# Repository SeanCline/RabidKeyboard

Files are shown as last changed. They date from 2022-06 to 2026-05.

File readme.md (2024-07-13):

# RabidKeyboard

This project is an ode to the old-school Cooler Master [QuickFire Rapid](https://deskthority.net/wiki/Cooler_Master_QuickFire_Rapid) TKL keyboard -- a board that introduced many people to the mechanical keyboard hobby years ago.

Over time, upgrade parts for these old mechanical keyboards have become hard to find. This project attempts to solve that by providing PCB designs that can be manufactured by services like [JLCPCB](https://jlcpcb.com/) or [PCBWay](https://www.pcbway.com/).

With the PCBs in this repository, you could:
 - Build a TKL keyboard from scratch.
 - Replace the mini-USB plug with USB-C on your Cooler Master QFR.
 - Replace the PCB in your QFR (or compatible) with a custom design running the [KMK firmware](https://github.com/KMKfw/kmk_firmware).
 - Replace the plate in your TKL keyboard with one made of FR-4 and support for more stabilizers. (Stock Costar, Cherry Plate mount, or PCB mount when the PCB is also replaced.)

## PCB
The PCB is designed in [KiCad](https://www.kicad.org/) to be easily soldered by hand. At its heart is the [RP2040 Stamp](https://www.lectronz.com/products/rp2040-stamp), which fits nicely beside the arrow keys.

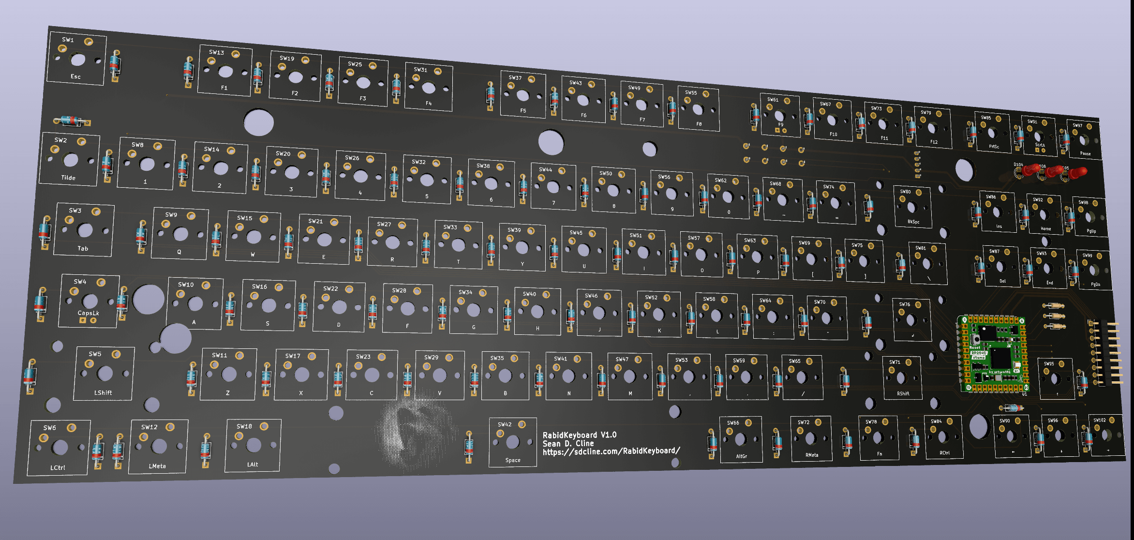
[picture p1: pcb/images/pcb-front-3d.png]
PCB 3D Render


## Plate
The plate is just a PCB without any copper traces. When sending it for manufacture, you can select the thickness of FR-4 to get the level of flex you like.

It's generated by copying the User.1 layer out of the PCB design and changing the layer to Edge.Cuts. The keyswitch footprints use the User.1 layer for the plate cutout which makes sure the plate cutouts always line up with the key switch location on the PCB.

> Note: This abuses the routing capabilities of a PCB manufacturer, so they'll likely charge extra for their trouble.

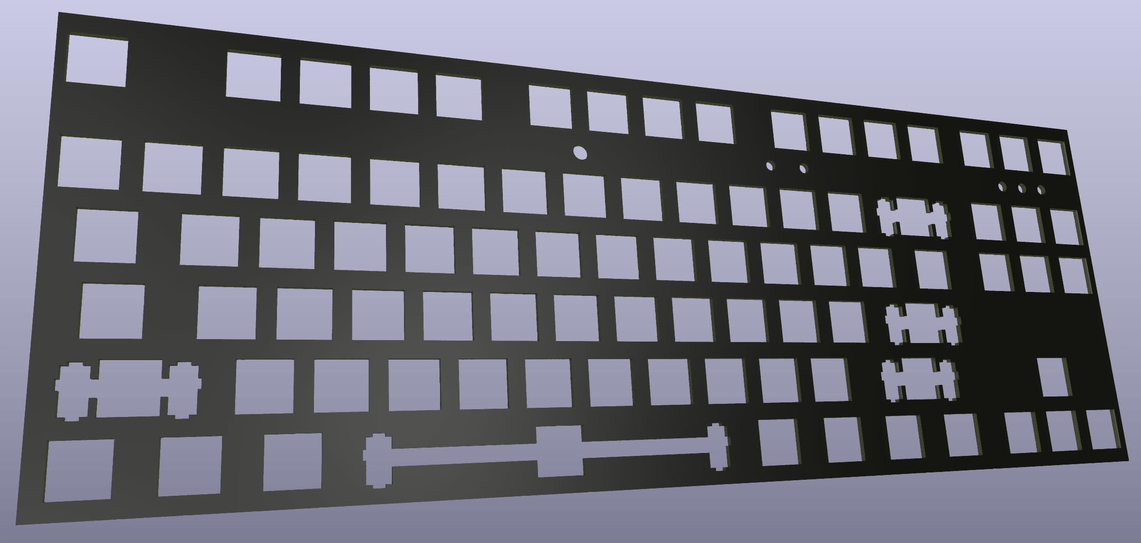
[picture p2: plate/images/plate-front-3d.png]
Plate 3D Render


## Costar USB-C Daughterboard
This PCB replaces the original mini-USB daughterboard in the Cooler Master QFR. Mounting holes match the [original PCB](reference/Quickfire%20Rapid/USB%20Daughterboard%20-%20Front.jpg) so it's a drop-in replacement. A little bit of filing is required to widen the mini-USB hole the width of the USB-C port.

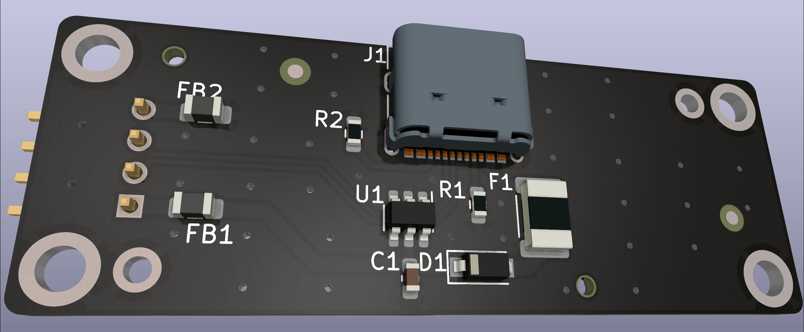
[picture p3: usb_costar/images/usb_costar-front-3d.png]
Costar USB-C Front 3D Render

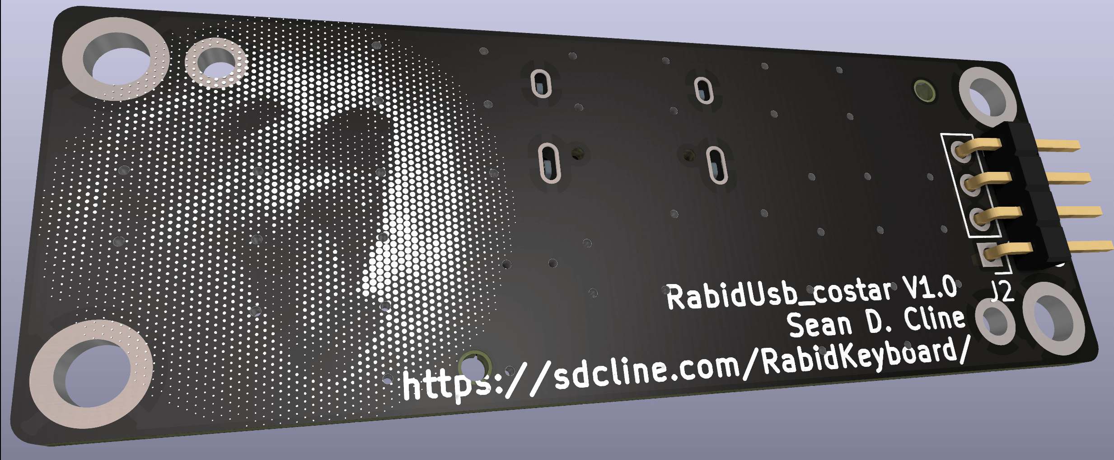
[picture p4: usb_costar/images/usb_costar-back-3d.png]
Costar USB-C Back 3D Render


## YMDK USB-C Daughterboard
Just like the Cooler Master QFR, Filco Majestouch 2, and KBParadise V80, the RabidKeyboard PCB in this repo fits into the YMDK F87 aluminum case.
[[Amazon]](https://amzn.com/dp/B06XNTWXWL)
[[AliExpress]](https://www.aliexpress.us/item/2251832431251957.html)
[[Ymdkey]](https://ymdkey.com/products/f87-tkl-cnc-anodized-aluminum-case-for-filco-cm-cooler-master-87-tenkeyless)

Unfortunately, the USB daughterboard that [comes with](reference/YMDK/YMDK%20Usb%20-%20Back.png) the YMDK F87 case lacks the [required 5.1k resistors](https://hackaday.com/2023/01/04/all-about-usb-c-resistors-and-emarkers/). It works fine when plugged in using a USB-C to Type-A cable, but does not function when plugged in using a USB-C to USB-C cable. It also lacks protection circuitry. The design in this repository is a drop in replacement with some improvements:
 - 5.1k CC1 and CC2 sense resistors to work with USB-C cables.
 - [TVS diodes](https://en.wikipedia.org/wiki/Surge_protector#Transient_voltage_suppressor) to keep static shocks from reaching the microcontroller.
 - 500mA polyfuse to protect from short circuits.
 - Reverse polarity protection diode.
 - Ferrite beads to reduce high frequency EMI.

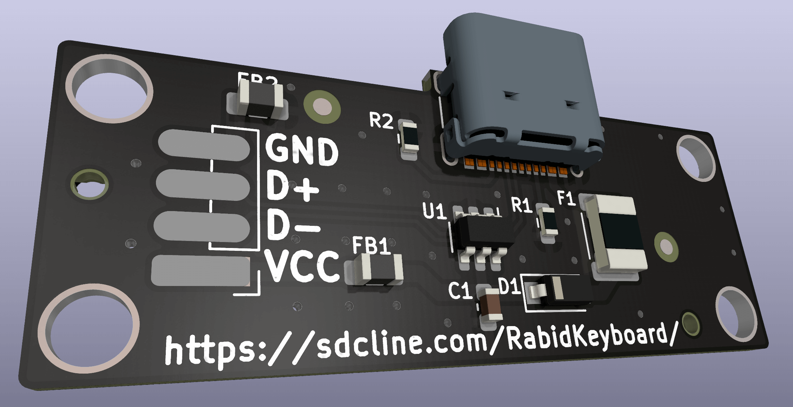
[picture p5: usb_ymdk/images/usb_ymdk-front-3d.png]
YMDK USB-C Front 3D Render

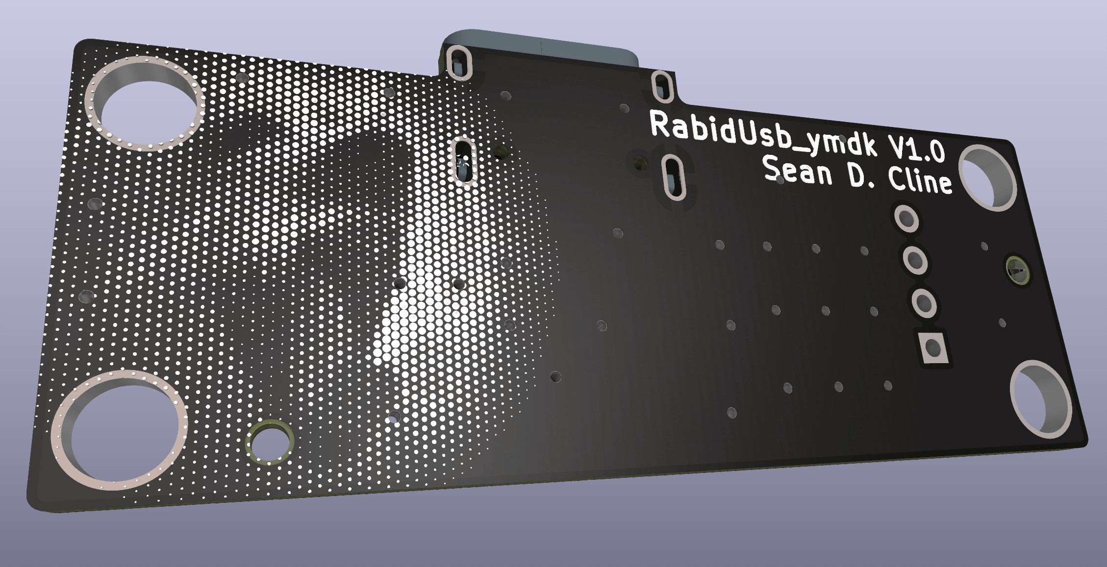
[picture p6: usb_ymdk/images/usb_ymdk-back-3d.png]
YMDK USB-C Back 3D Render


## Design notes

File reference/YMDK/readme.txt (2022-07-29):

These reference photos come from the YMDK F87, an anodized aluminum case for the Cooler Master Quickfire Rapid or Filco Majestouch TKL keyboard.

https://www.aliexpress.com/item/2251832781338162.html
https://www.aliexpress.com/item/2251832431251957.html
https://ymdkey.com/collections/case/products/cnc-anodized-aluminum-case-shell-for-filco-cm-cooler-master-87-tenkeyless-mechanical-keyboard-including-detachable-usb-m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

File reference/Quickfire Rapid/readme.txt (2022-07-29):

These are high-quality scans of the old school Cooler Master Quickfire Rapid TKL Keyboard.
The board was manufactured by Costar, the same company the manufactured the popular Filco Majestouch, WASD V1, Das Keyboard III, and Rosewill RK9000.

https://deskthority.net/wiki/Cooler_Master_QuickFire_Rapid
https://deskthority.net/wiki/Costar
https://www.coolermaster.com/catalog/peripheral/keyboards/quick-fire-rapid/

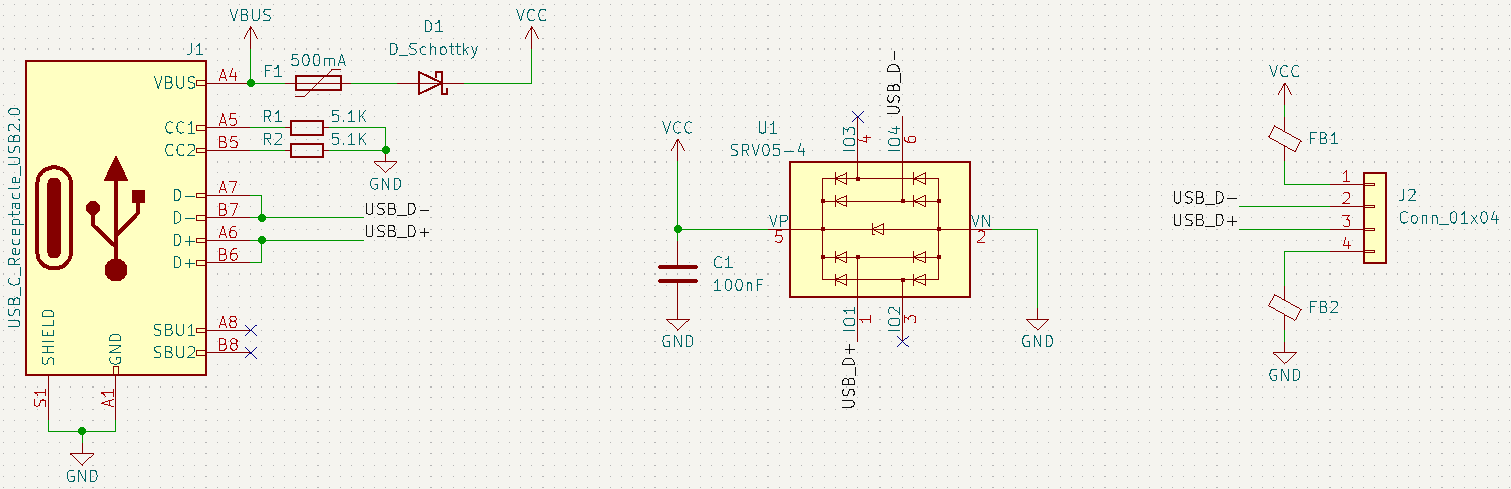
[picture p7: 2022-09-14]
usb_ymdk/images/usb_ymdk-schematic.png

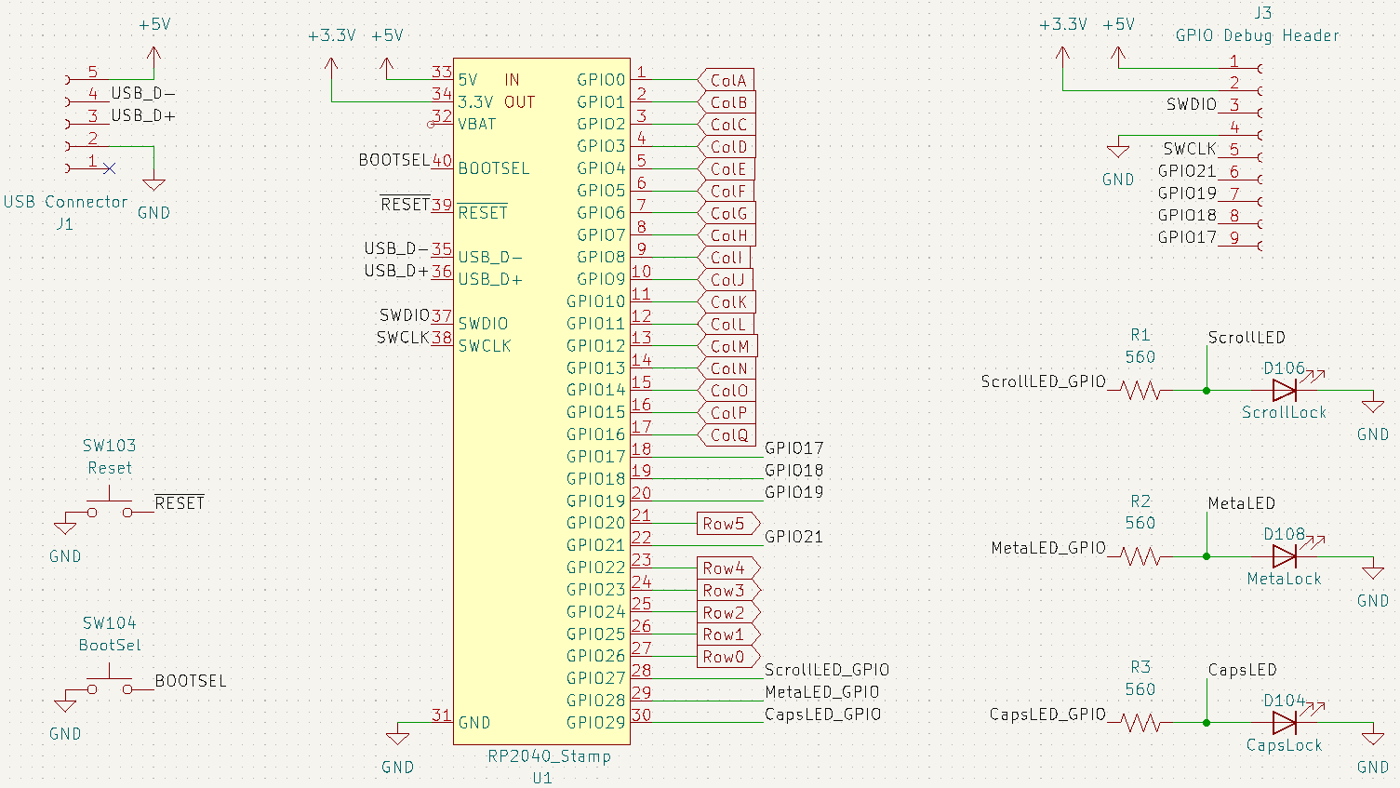
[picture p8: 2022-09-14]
pcb/images/pcb-schematic.png

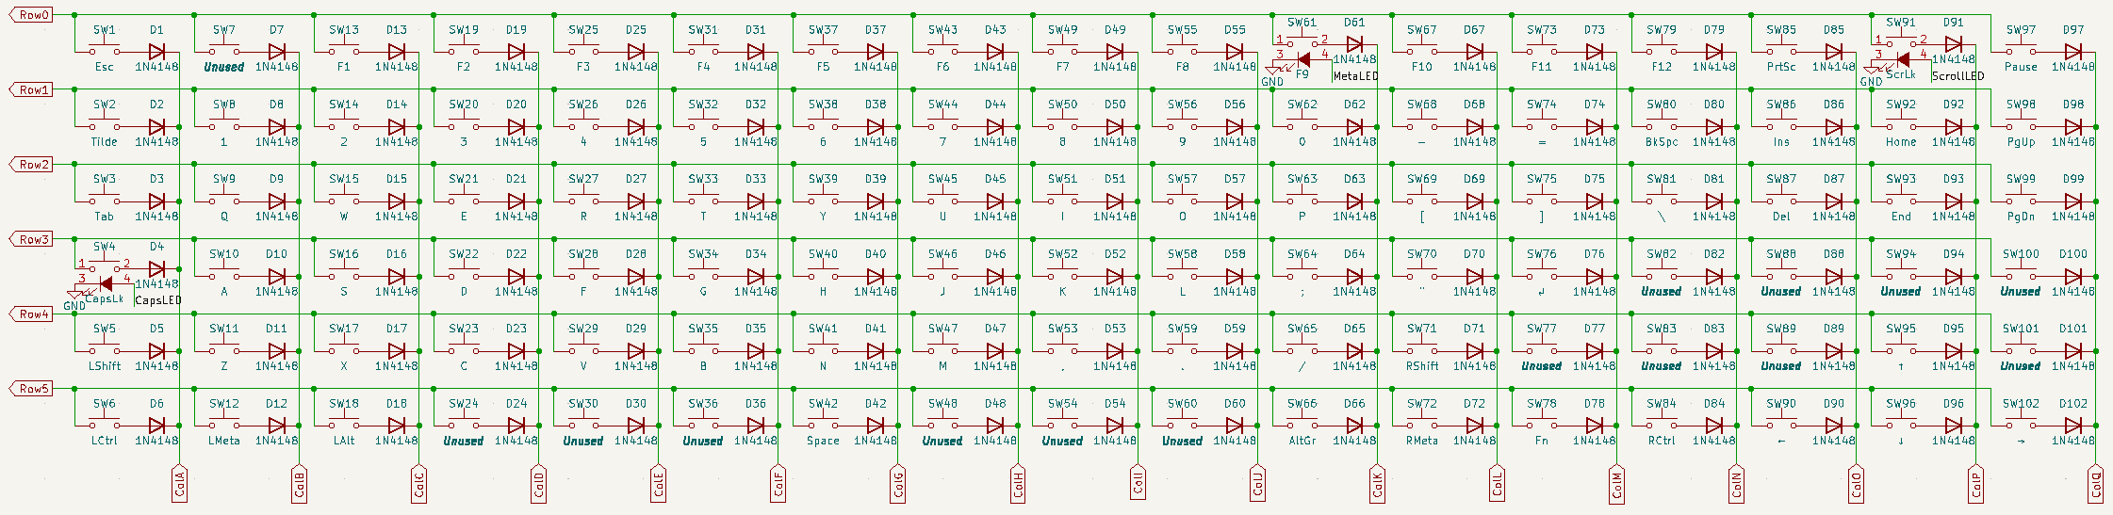
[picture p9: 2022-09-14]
pcb/images/pcb-schematic-matrix.png

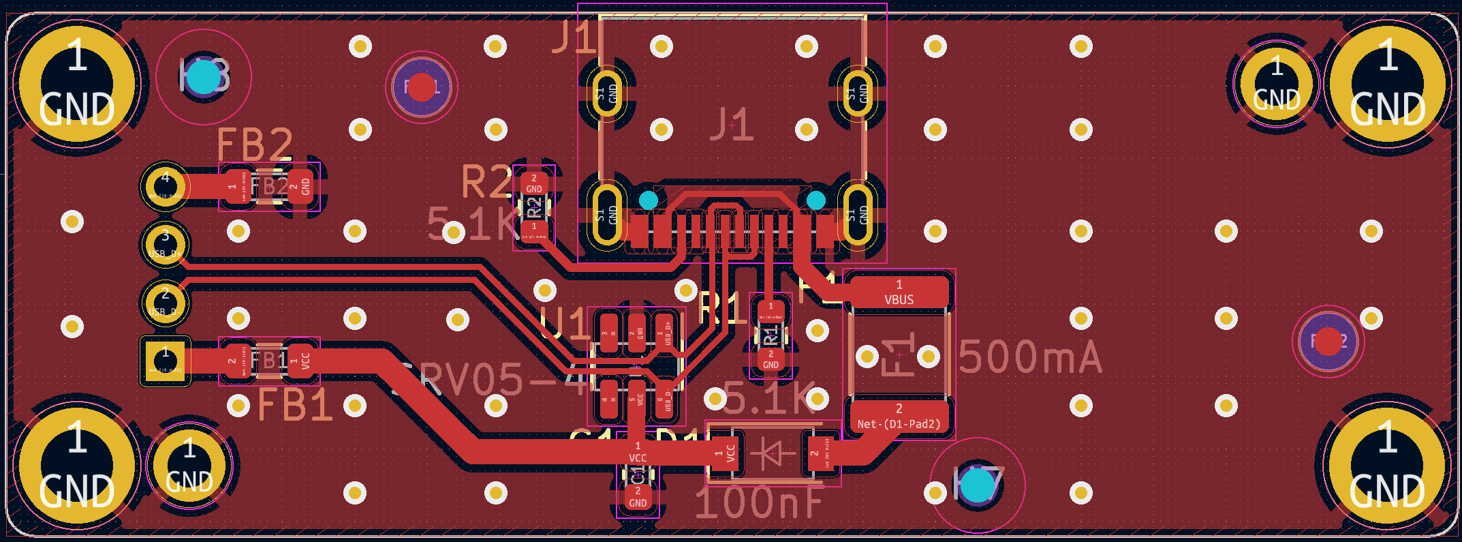
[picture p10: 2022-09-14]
usb_costar/images/usb_costar-front.png

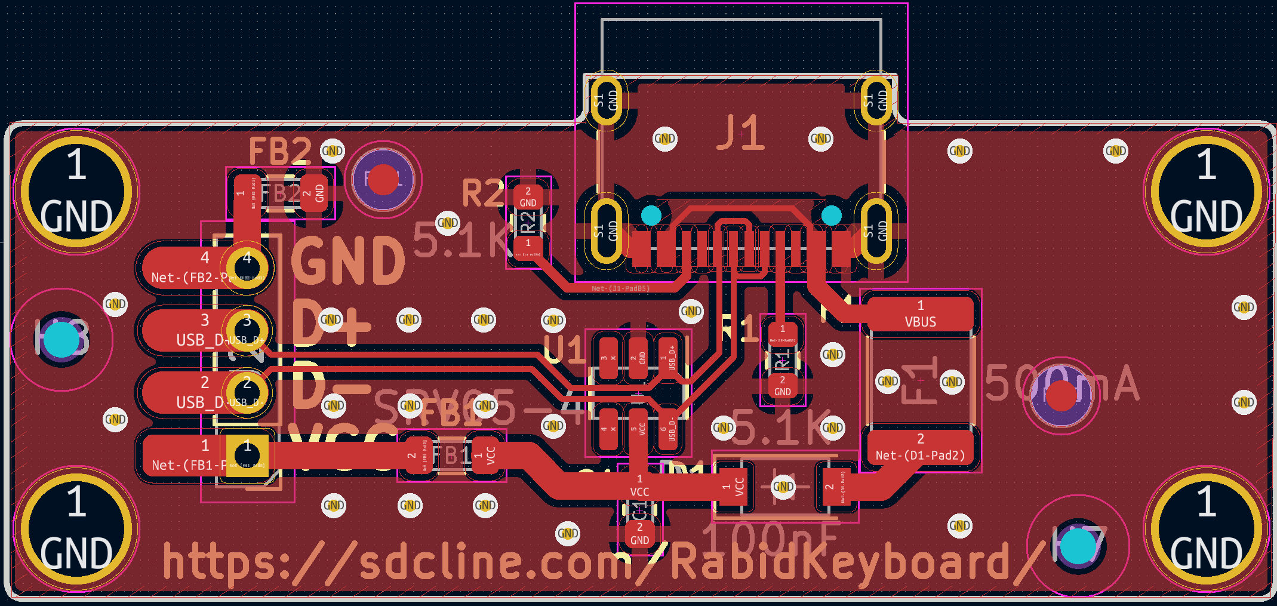
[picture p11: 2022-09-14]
usb_ymdk/images/usb_ymdk-front.png

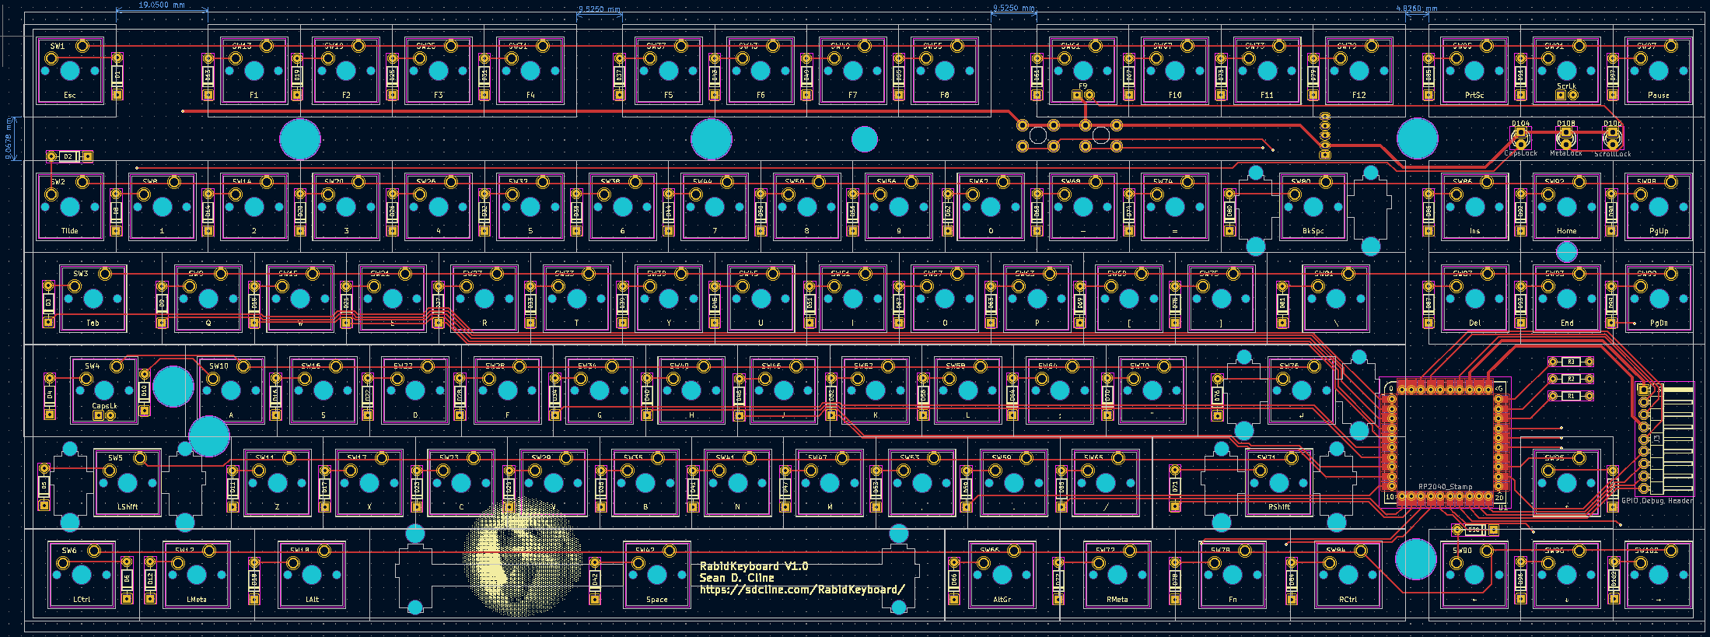
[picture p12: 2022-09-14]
pcb/images/pcb-front.png

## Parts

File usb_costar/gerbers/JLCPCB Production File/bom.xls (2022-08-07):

Comment | Designator | Footprint | JLCPCB Part #
100nF | C1 | Capacitor_SMD:C_0603_1608Metric | C14663
USB_C_Receptacle_USB2.0 | J1 | Connector_USB:USB_C_Receptacle_XKB_U262-16XN-4BVC11 | C319148
D_Schottky | D1 | Diode_SMD:D_SOD-123 | C8598
5.1K | R1,R2 | Resistor_SMD:R_0603_1608Metric | C23186
SRV05-4 | U1 | Package_TO_SOT_SMD:SOT-23-6 | C85364
500mA | F1 | Fuse:Fuse_1812_4532Metric | C12559

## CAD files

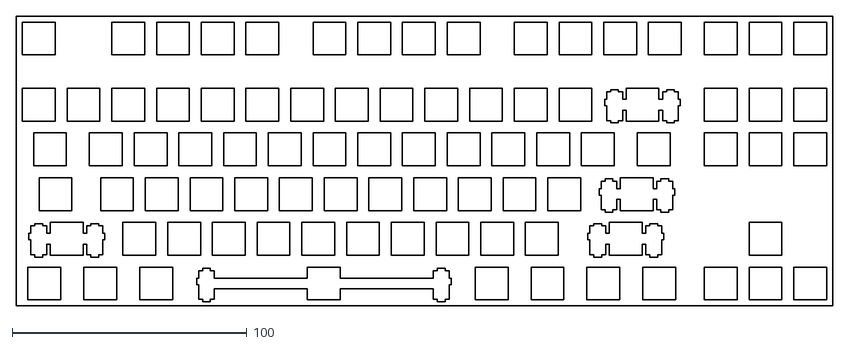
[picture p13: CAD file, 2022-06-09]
reference/builder.swillkb.com.dxf
347.7 x 123.4

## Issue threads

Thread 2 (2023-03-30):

Export plate to .step file format

EagleVee, 2023-03-30:
Hi, I'm new but how can I export the plate file to .step format?

SeanCline, 2023-03-31:
Oh, that's super easy. With the plate PCB open in Kicad, there's a `File->Export->Step` option in the menu.

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

Here's the exported [RabidPlate.step](https://github.com/SeanCline/RabidKeyboard/files/11125292/RabidPlate.zip)

If you're doing something more custom than the RabidKeyboard, you might have better luck starting with http://www.keyboard-layout-editor.com/ and taking the layout to http://builder.swillkb.com/ to generate CAD files of the plate.

EagleVee, 2023-04-01:
Nice, thank you very much! I haven't used Kicad before so I kinda lost.

Closed 2023-04-01.

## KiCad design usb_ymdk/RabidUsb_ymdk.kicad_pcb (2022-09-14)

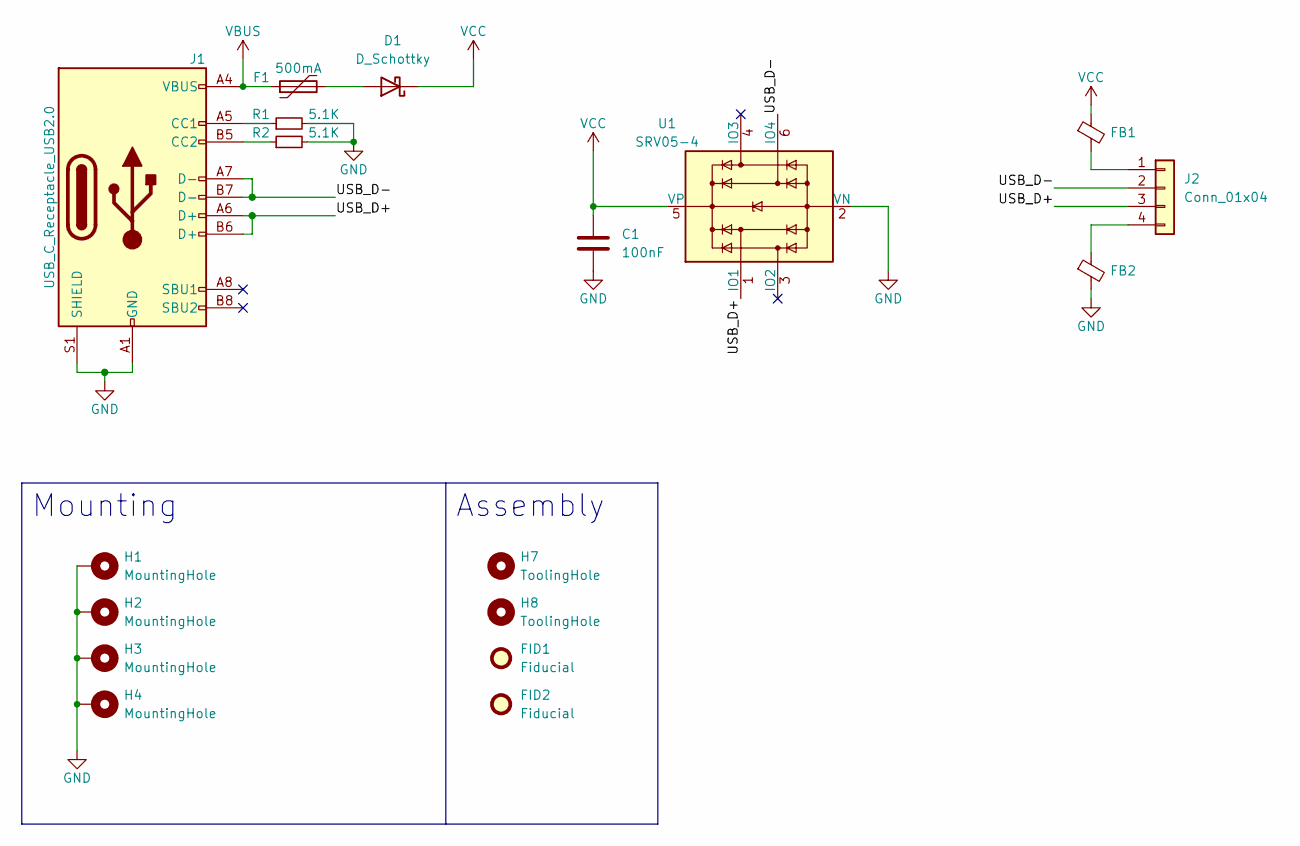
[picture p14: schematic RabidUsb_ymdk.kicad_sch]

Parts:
C1: 100nF; C_0603_1608Metric; LCSC C14663
D1: D_Schottky; D_SOD-123; LCSC C8598
F1: 500mA; Fuse_1812_4532Metric; LCSC C12559
FB1, FB2: FerriteBead_Small; L_0805_2012Metric; LCSC C67451
FID1, FID2: Fiducial; Fiducial_1mm_Mask2mm
H1, H2, H3, H4: MountingHole; MountingHole_.12in_Pad_.02in
H7, H8: ToolingHole; ToolingHole_1.152mm
J1: USB_C_Receptacle_USB2.0; USB_C_Receptacle_XKB_U262-16XN-4BVC11; LCSC C319148
J2: Conn_01x04; PinHeader_1x04_P2.00mm_Fingers
R1, R2: 5.1K; R_0603_1608Metric; LCSC C23186
U1: SRV05-4; SOT-23-6; LCSC C85364

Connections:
/USB_D+: J1.A6 (D+), J1.B6 (D+), J2.3, U1.1 (IO1)
/USB_D-: J1.A7 (D-), J1.B7 (D-), J2.2, U1.6 (IO4)
GND: C1.2, FB2.2, H1.1, H2.1, H3.1, H4.1, J1.A1 (GND), J1.A12 (GND), J1.B1 (GND), J1.B12 (GND), J1.S1 (SHIELD), R1.2, R2.2, U1.2 (VN)
unnamed: D1.2 (A), F1.2
unnamed: FB1.2, J2.1
unnamed: FB2.1, J2.4
unnamed: J1.A5 (CC1), R1.1
unnamed: J1.B5 (CC2), R2.1
VBUS: F1.1, J1.A4 (VBUS), J1.A9 (VBUS), J1.B4 (VBUS), J1.B9 (VBUS)
VCC: C1.1, D1.1 (K), FB1.1, U1.5 (VP)

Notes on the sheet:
Assembly
Mounting

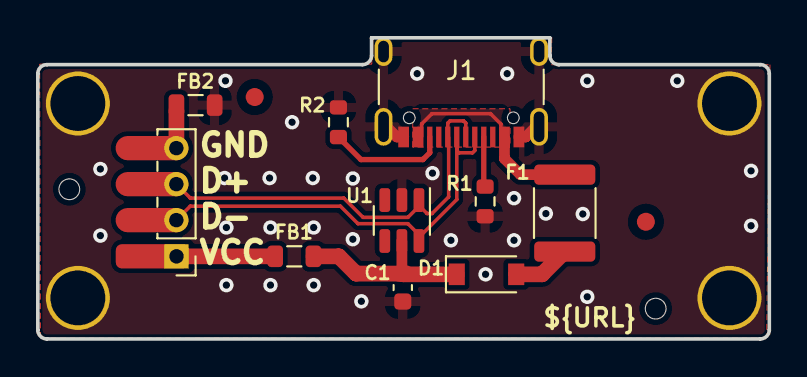
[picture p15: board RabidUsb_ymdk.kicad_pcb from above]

Board: 2 copper layers, 40.6 x 16.7 mm, 18 parts (0 on the bottom side), 10 nets.

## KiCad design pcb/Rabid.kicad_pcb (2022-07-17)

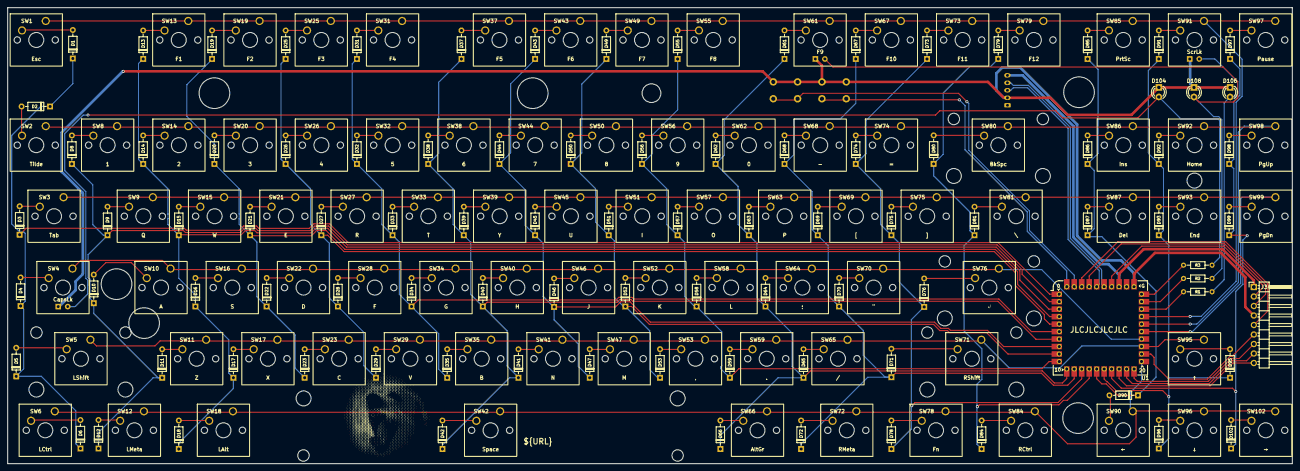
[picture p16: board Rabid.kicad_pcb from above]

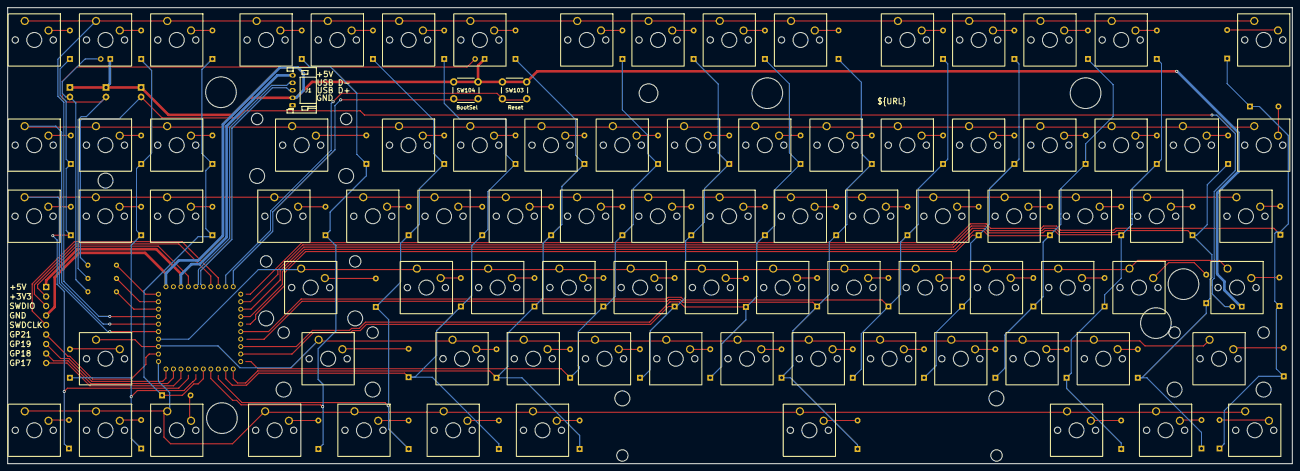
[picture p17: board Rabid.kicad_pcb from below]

Board: 2 copper layers, 343.4 x 121.9 mm, 194 parts (3 on the bottom side), 129 nets.

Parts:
D1, D2, D3, D4, D5, D6, D8, D9, D10, D11, D12, D13, D14, D15, D16, D17, D18, D19, D20, D21, D22, D23, D25, D26, D27, D28, D29, D31, D32, D33, D34, D35, D37, D38, D39, D40, D41, D42, D43, D44, D45, D46, D47, D49, D50, D51, D52, D53, D55, D56, D57, D58, D59, D61, D62, D63, D64, D65, D66, D67, D68, D69, D70, D71, D72, D73, D74, D75, D76, D78, D79, D80, D81, D84, D85, D86, D87, D90, D91, D92, D93, D95, D96, D97, D98, D99, D102: 1N4148; D_DO-35_SOD27_P7.62mm_Horizontal
D104: CapsLock; LED_D3.0mm
D106: ScrollLock; LED_D3.0mm
D108: MetaLock; LED_D3.0mm
G1: LOGO; RabidKeyboardLogo
H1, H2, H4, H5, H6, H7: MountingHole_8.2mm
H3: MountingHole_5mm
H8: MountingHole_4mm
J1: USB Connector; JST_PH_S5B-PH-K_1x05_P2.00mm_Horizontal
J3: GPIO Debug Header; PinHeader_1x09_P2.54mm_Horizontal
R1, R2, R3: 560; R_Axial_DIN0204_L3.6mm_D1.6mm_P7.62mm_Horizontal
SW1: Esc; SW_Cherry_MX_1.00u_PCB
SW2: Tilde; SW_Cherry_MX_1.00u_PCB
SW3: Tab; SW_Cherry_MX_1.50u_PCB
SW4: CapsLk; SW_Cherry_MX_1.75u_PCB_LED
SW5: LShift; SW_Cherry_MX_2.25u_PCB
SW6: LCtrl; SW_Cherry_MX_1.25u_PCB
SW8: 1; SW_Cherry_MX_1.00u_PCB
SW9: Q; SW_Cherry_MX_1.00u_PCB
SW10: A; SW_Cherry_MX_1.00u_PCB
SW11: Z; SW_Cherry_MX_1.00u_PCB
SW12: LMeta; SW_Cherry_MX_1.25u_PCB
SW13: F1; SW_Cherry_MX_1.00u_PCB
SW14: 2; SW_Cherry_MX_1.00u_PCB
SW15: W; SW_Cherry_MX_1.00u_PCB
SW16: S; SW_Cherry_MX_1.00u_PCB
SW17: X; SW_Cherry_MX_1.00u_PCB
SW18: LAlt; SW_Cherry_MX_1.25u_PCB
SW19: F2; SW_Cherry_MX_1.00u_PCB
SW20: 3; SW_Cherry_MX_1.00u_PCB
SW21: E; SW_Cherry_MX_1.00u_PCB
SW22: D; SW_Cherry_MX_1.00u_PCB
SW23: C; SW_Cherry_MX_1.00u_PCB
SW25: F3; SW_Cherry_MX_1.00u_PCB
SW26: 4; SW_Cherry_MX_1.00u_PCB
SW27: R; SW_Cherry_MX_1.00u_PCB
SW28: F; SW_Cherry_MX_1.00u_PCB
SW29: V; SW_Cherry_MX_1.00u_PCB
SW31: F4; SW_Cherry_MX_1.00u_PCB
SW32: 5; SW_Cherry_MX_1.00u_PCB
SW33: T; SW_Cherry_MX_1.00u_PCB
SW34: G; SW_Cherry_MX_1.00u_PCB
SW35: B; SW_Cherry_MX_1.00u_PCB
SW37: F5; SW_Cherry_MX_1.00u_PCB
SW38: 6; SW_Cherry_MX_1.00u_PCB
SW39: Y; SW_Cherry_MX_1.00u_PCB
SW40: H; SW_Cherry_MX_1.00u_PCB
SW41: N; SW_Cherry_MX_1.00u_PCB
SW42: Space; SW_Cherry_MX_6.25u_PCB_MirroredStabs
SW43: F6; SW_Cherry_MX_1.00u_PCB
SW44: 7; SW_Cherry_MX_1.00u_PCB
SW45: U; SW_Cherry_MX_1.00u_PCB
SW46: J; SW_Cherry_MX_1.00u_PCB
SW47: M; SW_Cherry_MX_1.00u_PCB
SW49: F7; SW_Cherry_MX_1.00u_PCB
SW50: 8; SW_Cherry_MX_1.00u_PCB
SW51: I; SW_Cherry_MX_1.00u_PCB
SW52: K; SW_Cherry_MX_1.00u_PCB
SW53: ,; SW_Cherry_MX_1.00u_PCB
SW55: F8; SW_Cherry_MX_1.00u_PCB
SW56: 9; SW_Cherry_MX_1.00u_PCB
SW57: O; SW_Cherry_MX_1.00u_PCB
SW58: L; SW_Cherry_MX_1.00u_PCB
SW59: .; SW_Cherry_MX_1.00u_PCB
SW61: F9; SW_Cherry_MX_1.00u_PCB_LED
SW62: 0; SW_Cherry_MX_1.00u_PCB
SW63: P; SW_Cherry_MX_1.00u_PCB
SW64: ;; SW_Cherry_MX_1.00u_PCB
SW65: /; SW_Cherry_MX_1.00u_PCB
SW66: AltGr; SW_Cherry_MX_1.25u_PCB
SW67: F10; SW_Cherry_MX_1.00u_PCB
SW68: -; SW_Cherry_MX_1.00u_PCB
SW69: [; SW_Cherry_MX_1.00u_PCB
SW70: "; SW_Cherry_MX_1.00u_PCB
SW71: RShift; SW_Cherry_MX_2.75u_PCB
SW72: RMeta; SW_Cherry_MX_1.25u_PCB
SW73: F11; SW_Cherry_MX_1.00u_PCB
SW74: =; SW_Cherry_MX_1.00u_PCB
SW75: ]; SW_Cherry_MX_1.00u_PCB
SW76: ↲; SW_Cherry_MX_2.25u_PCB
SW78: Fn; SW_Cherry_MX_1.25u_PCB
SW79: F12; SW_Cherry_MX_1.00u_PCB
SW80: BkSpc; SW_Cherry_MX_2.00u_PCB
SW81: \; SW_Cherry_MX_1.50u_PCB
SW84: RCtrl; SW_Cherry_MX_1.25u_PCB
SW85: PrtSc; SW_Cherry_MX_1.00u_PCB
SW86: Ins; SW_Cherry_MX_1.00u_PCB
SW87: Del; SW_Cherry_MX_1.00u_PCB
SW90: ←; SW_Cherry_MX_1.00u_PCB
SW91: ScrLk; SW_Cherry_MX_1.00u_PCB_LED
SW92: Home; SW_Cherry_MX_1.00u_PCB
SW93: End; SW_Cherry_MX_1.00u_PCB
SW95: ↑; SW_Cherry_MX_1.00u_PCB
SW96: ↓; SW_Cherry_MX_1.00u_PCB
SW97: Pause; SW_Cherry_MX_1.00u_PCB
SW98: PgUp; SW_Cherry_MX_1.00u_PCB
SW99: PgDn; SW_Cherry_MX_1.00u_PCB
SW102: →; SW_Cherry_MX_1.00u_PCB
SW103: Reset; SW_PUSH_6mm
SW104: BootSel; SW_PUSH_6mm
U1: RP2040_Stamp; RP2040_Stamp_THT

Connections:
+3V3: J3.2, U1.34 (3.3V)
+5V: J1.5, J3.1, U1.33 (5V)
/BOOTSEL: SW104.2, U1.40 (BOOTSEL)
/CapsLED: D104.2 (A), R3.2, SW4.4 (A)
/CapsLED_GPIO: R3.1, U1.30 (GPIO29)
/GPIO17: J3.9, U1.18 (GPIO17)
/GPIO18: J3.8, U1.19 (GPIO18)
/GPIO19: J3.7, U1.20 (GPIO19)
/GPIO21: J3.6, U1.22 (GPIO21)
/MetaLED: D108.2 (A), R2.2, SW61.4 (A)
/MetaLED_GPIO: R2.1, U1.29 (GPIO28)
/SWCLK: J3.5, U1.38 (SWCLK)
/SWDIO: J3.3, U1.37 (SWDIO)
/ScrollLED: D106.2 (A), R1.2, SW91.4 (A)
/ScrollLED_GPIO: R1.1, U1.28 (GPIO27)
/USB_D+: J1.3, U1.36 (USB_D+)
/USB_D-: J1.4, U1.35 (USB_D-)
/~RESET: SW103.2, U1.39 (~RESET)
ColA: D1.1 (K), D2.1 (K), D3.1 (K), D4.1 (K), D5.1 (K), D6.1 (K), U1.1 (GPIO0)
ColB: D8.1 (K), D9.1 (K), D10.1 (K), D11.1 (K), D12.1 (K), U1.2 (GPIO1)
ColC: D13.1 (K), D14.1 (K), D15.1 (K), D16.1 (K), D17.1 (K), D18.1 (K), U1.3 (GPIO2)
ColD: D19.1 (K), D20.1 (K), D21.1 (K), D22.1 (K), D23.1 (K), U1.4 (GPIO3)
ColE: D25.1 (K), D26.1 (K), D27.1 (K), D28.1 (K), D29.1 (K), U1.5 (GPIO4)
ColF: D31.1 (K), D32.1 (K), D33.1 (K), D34.1 (K), D35.1 (K), U1.6 (GPIO5)
ColG: D37.1 (K), D38.1 (K), D39.1 (K), D40.1 (K), D41.1 (K), D42.1 (K), U1.7 (GPIO6)
ColH: D43.1 (K), D44.1 (K), D45.1 (K), D46.1 (K), D47.1 (K), U1.8 (GPIO7)
ColI: D49.1 (K), D50.1 (K), D51.1 (K), D52.1 (K), D53.1 (K), U1.9 (GPIO8)
ColJ: D55.1 (K), D56.1 (K), D57.1 (K), D58.1 (K), D59.1 (K), U1.10 (GPIO9)
ColK: D61.1 (K), D62.1 (K), D63.1 (K), D64.1 (K), D65.1 (K), D66.1 (K), U1.11 (GPIO10)
ColL: D67.1 (K), D68.1 (K), D69.1 (K), D70.1 (K), D71.1 (K), D72.1 (K), U1.12 (GPIO11)
ColM: D73.1 (K), D74.1 (K), D75.1 (K), D76.1 (K), D78.1 (K), U1.13 (GPIO12)
ColN: D79.1 (K), D80.1 (K), D81.1 (K), D84.1 (K), U1.14 (GPIO13)
ColO: D85.1 (K), D86.1 (K), D87.1 (K), D90.1 (K), U1.15 (GPIO14)
ColP: D91.1 (K), D92.1 (K), D93.1 (K), D95.1 (K), D96.1 (K), U1.16 (GPIO15)
ColQ: D97.1 (K), D98.1 (K), D99.1 (K), D102.1 (K), U1.17 (GPIO16)
GND: D104.1 (K), D106.1 (K), D108.1 (K), J1.2, J3.4, SW4.3 (K), SW61.3 (K), SW91.3 (K), SW103.1, SW104.1, U1.31 (GND)
unnamed: D1.2 (A), SW1.2
unnamed: D2.2 (A), SW2.2
unnamed: D3.2 (A), SW3.2
unnamed: D4.2 (A), SW4.2
unnamed: D5.2 (A), SW5.2
unnamed: D6.2 (A), SW6.2
unnamed: D8.2 (A), SW8.2
unnamed: D9.2 (A), SW9.2
unnamed: D10.2 (A), SW10.2
unnamed: D11.2 (A), SW11.2
unnamed: D12.2 (A), SW12.2
unnamed: D13.2 (A), SW13.2
unnamed: D14.2 (A), SW14.2
unnamed: D15.2 (A), SW15.2
unnamed: D16.2 (A), SW16.2
unnamed: D17.2 (A), SW17.2
unnamed: D18.2 (A), SW18.2
unnamed: D19.2 (A), SW19.2
unnamed: D20.2 (A), SW20.2
unnamed: D21.2 (A), SW21.2
unnamed: D22.2 (A), SW22.2
unnamed: D23.2 (A), SW23.2
unnamed: D25.2 (A), SW25.2
unnamed: D26.2 (A), SW26.2
unnamed: D27.2 (A), SW27.2
unnamed: D28.2 (A), SW28.2
unnamed: D29.2 (A), SW29.2
unnamed: D31.2 (A), SW31.2
unnamed: D32.2 (A), SW32.2
unnamed: D33.2 (A), SW33.2
unnamed: D34.2 (A), SW34.2
unnamed: D35.2 (A), SW35.2
unnamed: D37.2 (A), SW37.2
unnamed: D38.2 (A), SW38.2
unnamed: D39.2 (A), SW39.2
unnamed: D40.2 (A), SW40.2
unnamed: D41.2 (A), SW41.2
unnamed: D42.2 (A), SW42.2
unnamed: D43.2 (A), SW43.2
unnamed: D44.2 (A), SW44.2
unnamed: D45.2 (A), SW45.2
unnamed: D46.2 (A), SW46.2
unnamed: D47.2 (A), SW47.2
unnamed: D49.2 (A), SW49.2
unnamed: D50.2 (A), SW50.2
unnamed: D51.2 (A), SW51.2
unnamed: D52.2 (A), SW52.2
unnamed: D53.2 (A), SW53.2
unnamed: D55.2 (A), SW55.2
unnamed: D56.2 (A), SW56.2
unnamed: D57.2 (A), SW57.2
unnamed: D58.2 (A), SW58.2
unnamed: D59.2 (A), SW59.2
unnamed: D61.2 (A), SW61.2
unnamed: D62.2 (A), SW62.2
unnamed: D63.2 (A), SW63.2
unnamed: D64.2 (A), SW64.2
unnamed: D65.2 (A), SW65.2
unnamed: D66.2 (A), SW66.2
unnamed: D67.2 (A), SW67.2
unnamed: D68.2 (A), SW68.2
unnamed: D69.2 (A), SW69.2
unnamed: D70.2 (A), SW70.2
unnamed: D71.2 (A), SW71.2
unnamed: D72.2 (A), SW72.2
unnamed: D73.2 (A), SW73.2
unnamed: D74.2 (A), SW74.2
unnamed: D75.2 (A), SW75.2
unnamed: D76.2 (A), SW76.2
unnamed: D78.2 (A), SW78.2
unnamed: D79.2 (A), SW79.2
unnamed: D80.2 (A), SW80.2
unnamed: D81.2 (A), SW81.2
unnamed: D84.2 (A), SW84.2
unnamed: D85.2 (A), SW85.2
unnamed: D86.2 (A), SW86.2
unnamed: D87.2 (A), SW87.2
unnamed: D90.2 (A), SW90.2
unnamed: D91.2 (A), SW91.2
unnamed: D92.2 (A), SW92.2
unnamed: D93.2 (A), SW93.2
unnamed: D95.2 (A), SW95.2
unnamed: D96.2 (A), SW96.2
unnamed: D97.2 (A), SW97.2
unnamed: D98.2 (A), SW98.2
unnamed: D99.2 (A), SW99.2
unnamed: D102.2 (A), SW102.2
Row0: SW1.1, SW13.1, SW19.1, SW25.1, SW31.1, SW37.1, SW43.1, SW49.1, SW55.1, SW61.1, SW67.1, SW73.1, SW79.1, SW85.1, SW91.1, SW97.1, U1.27 (GPIO26)
Row1: SW2.1, SW8.1, SW14.1, SW20.1, SW26.1, SW32.1, SW38.1, SW44.1, SW50.1, SW56.1, SW62.1, SW68.1, SW74.1, SW80.1, SW86.1, SW92.1, SW98.1, U1.26 (GPIO25)
Row2: SW3.1, SW9.1, SW15.1, SW21.1, SW27.1, SW33.1, SW39.1, SW45.1, SW51.1, SW57.1, SW63.1, SW69.1, SW75.1, SW81.1, SW87.1, SW93.1, SW99.1, U1.25 (GPIO24)
Row3: SW4.1, SW10.1, SW16.1, SW22.1, SW28.1, SW34.1, SW40.1, SW46.1, SW52.1, SW58.1, SW64.1, SW70.1, SW76.1, U1.24 (GPIO23)
Row4: SW5.1, SW11.1, SW17.1, SW23.1, SW29.1, SW35.1, SW41.1, SW47.1, SW53.1, SW59.1, SW65.1, SW71.1, SW95.1, U1.23 (GPIO22)
Row5: SW6.1, SW12.1, SW18.1, SW42.1, SW66.1, SW72.1, SW78.1, SW84.1, SW90.1, SW96.1, SW102.1, U1.21 (GPIO20)

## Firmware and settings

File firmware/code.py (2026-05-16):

# RabidKeyboard
# https://sdcline.com/RabidKeyboard
import board
import time
import digitalio
import pwmio
import math
import supervisor
import microcontroller
from microcontroller import Pin

from kmk.kmk_keyboard import KMKKeyboard
from kmk.scanners import DiodeOrientation
from kmk.scanners.keypad import MatrixScanner
from kmk.keys import KC
from kmk.modules.layers import Layers
from kmk.extensions import Extension
from kmk.extensions.media_keys import MediaKeys
from kmk.extensions.lock_status import LockStatus
from kmk.modules.dynamic_sequences import DynamicSequences
from kmk.modules.mouse_jiggler import MouseJiggler

# Set up the key matrix.
class KMKRabidKeyboard(KMKKeyboard):
    def __init__(self):
        super().__init__()

        self.col_pins = (
            board.GP0, board.GP1, board.GP2, board.GP3, board.GP4, board.GP5, board.GP6,
            board.GP7, board.GP8, board.GP9, board.GP10, board.GP11, board.GP12, board.GP13,
            board.GP14, board.GP15, board.GP16
        )

        self.row_pins = (
            board.GP26, board.GP25, board.GP24, board.GP23, board.GP22, board.GP20
        )

        self.diode_orientation = DiodeOrientation.ROW2COL
        
        self.matrix = [MatrixScanner(
            column_pins=self.col_pins,
            row_pins=self.row_pins,
            columns_to_anodes=self.diode_orientation,
            interval=0.01,
            debounce_threshold=3,
            max_events=64
        )]

keyboard = KMKRabidKeyboard()

# Set up the mappings in each layer.
keyboard.modules.append(Layers())
keyboard.extensions.append(MediaKeys())

dyn_seq = DynamicSequences(
    slots=10, # The number of sequence slots to use
    timeout=60000,  # Maximum time to spend in record or config mode before stopping automatically, milliseconds
    key_interval=25,  # Milliseconds between key events while playing
    use_recorded_speed=False,  # Whether to play the sequence at the speed it was typed
)
keyboard.modules.append(dyn_seq)

# Set up the Mouse Jiggler.
jiggler = MouseJiggler()
keyboard.modules.append(jiggler)

# Define the layer-switching keys.
Fn = KC.MO(2)
MetaLock = KC.TG(1)

# Layer 0: Base layer is the typical key map.
base_layer = [
    KC.ESC, KC.NO, KC.F1, KC.F2, KC.F3, KC.F4, KC.F5, KC.F6, KC.F7, KC.F8, KC.F9, KC.F10, KC.F11, KC.F12, KC.PSCR, KC.SLCK, KC.BRK,
    KC.GRV, KC.N1, KC.N2, KC.N3, KC.N4, KC.N5, KC.N6, KC.N7, KC.N8, KC.N9, KC.N0, KC.MINS, KC.EQL, KC.BSPC, KC.INS, KC.HOME, KC.PGUP,
    KC.TAB, KC.Q, KC.W, KC.E, KC.R, KC.T, KC.Y, KC.U, KC.I, KC.O, KC.P, KC.LBRC, KC.RBRC, KC.BSLS, KC.DEL, KC.END, KC.PGDN,
    KC.CAPS, KC.A, KC.S, KC.D, KC.F, KC.G, KC.H, KC.J, KC.K, KC.L, KC.SCLN, KC.QUOT, KC.ENT, KC.NO, KC.NO, KC.NO, KC.NO,
    KC.LSFT, KC.Z, KC.X, KC.C, KC.V, KC.B, KC.N, KC.M, KC.COMM, KC.DOT, KC.SLSH, KC.RSFT, KC.NO, KC.NO, KC.NO, KC.UP, KC.NO,
    KC.LCTL, KC.LGUI, KC.LALT, KC.NO, KC.NO, KC.NO, KC.SPC, KC.NO, KC.NO, KC.NO, KC.RALT, KC.RGUI, Fn, KC.RCTL, KC.LEFT, KC.DOWN, KC.RIGHT,
]

# Layer 1: Meta-lock layer disables RGUI/LGUI but is otherwise transparent to the base layer.
def transparentUnlessMeta(kc):
    return KC.NO if (kc == KC.LGUI or kc == KC.RGUI) else KC.TRNS

metalock_layer = [transparentUnlessMeta(kc) for kc in base_layer]

# Layer 2: Active while Fn key is held.
SEQ_REC = KC.RECORD_SEQUENCE()
SEQ_STP = KC.STOP_SEQUENCE()
SEQ_PLY = KC.PLAY_SEQUENCE()
SEQ_SET = KC.SET_SEQUENCE
fn_layer = [
    KC.RESET, KC.NO, KC.BOOTLOADER, KC.NO, KC.NO, KC.NO, KC.MPLY, KC.MSTP, KC.MPRV, KC.MNXT, MetaLock, KC.MUTE, KC.VOLD, KC.VOLU, KC.NO, KC.MJ_TOGGLE, KC.NO,
    SEQ_REC, SEQ_SET(1), SEQ_SET(2), SEQ_SET(3),  SEQ_SET(4),  SEQ_SET(5),  SEQ_SET(6),  SEQ_SET(7), SEQ_SET(8), SEQ_SET(9), SEQ_SET(0), KC.NO, KC.NO, SEQ_STP, KC.NO, KC.NO, KC.NO,
    KC.NO, KC.NO, KC.NO, KC.NO, KC.NO, KC.NO, KC.NO, KC.NO, KC.NO, KC.NO, KC.NO, KC.NO, KC.NO, KC.NO, KC.NO, KC.NO, KC.NO,
    KC.NO, KC.NO, KC.NO, KC.NO, KC.NO, KC.NO, KC.NO, KC.NO, KC.NO, KC.NO, KC.NO, KC.NO, SEQ_PLY, KC.NO, KC.NO, KC.NO, KC.NO,
    KC.NO, KC.NO, KC.NO, KC.NO, KC.NO, KC.NO, KC.NO, KC.NO, KC.NO, KC.NO, KC.NO, KC.NO, KC.NO, KC.NO, KC.NO, KC.NO, KC.NO,
    KC.NO, KC.NO, KC.NO, KC.NO, KC.NO, KC.NO, KC.NO, KC.NO, KC.NO, KC.NO, KC.NO, KC.NO, KC.NO, KC.NO, KC.NO, KC.NO, KC.NO,
]

# Finish up the layers.
keyboard.keymap = [base_layer, metalock_layer, fn_layer]

# Define an extension that keeps the Caps, Scroll, and Meta lock LEDs synched with the keyboard/HID state.
class LockStatusLeds(LockStatus):
    def __init__(self, caps_led : Pin, meta_led : Pin, scroll_led : Pin, jiggler : MouseJiggler = None):
        super().__init__()
        self.caps_led = digitalio.DigitalInOut(caps_led)
        self.caps_led.direction = digitalio.Direction.OUTPUT
        self.meta_led = digitalio.DigitalInOut(meta_led)
        self.meta_led.direction = digitalio.Direction.OUTPUT
        self.scroll_led = pwmio.PWMOut(scroll_led)
        self._jiggler = jiggler
        self._prev_jiggle_state = None
        self._last_fade_tick = 0
        self.fade_interval = .01
        
    def after_hid_send(self, sandbox):
        super().after_hid_send(sandbox)
        
        # Throttle status led updates.
        ticks_ms = supervisor.ticks_ms()
        ticks_since_last_fade = ticks_ms - self._last_fade_tick
        if (ticks_since_last_fade > 0 and ticks_since_last_fade < 30):
            return
        self._last_fade_tick = ticks_ms

        # Caps Lock
        self.caps_led.value = self.get_caps_lock()
        
        # Meta Lock
        self.meta_led.value = (1 in sandbox.active_layers)
        
        # Scroll Lock & Jiggle
        jiggle_on = self._jiggler is not None and self._jiggler.is_jiggling
        if jiggle_on:
            fade_ticks = ticks_ms & 0xFFFF # Truncate the high bits so conversion to float doesn't lose precision.
            self.scroll_led.duty_cycle = int((math.sin(fade_ticks*self.fade_interval)+1)/2 * 65535)
            self._prev_jiggle_state = jiggle_on
        elif jiggle_on != self._prev_jiggle_state:
            self.scroll_led.duty_cycle = 0
            self._prev_jiggle_state = jiggle_on
        else:
            self.scroll_led.duty_cycle = self.get_scroll_lock() * 65535

keyboard.extensions.append(LockStatusLeds(board.A3, board.GP28, board.GP27, jiggler))

def wait_for_usb():
    """https://github.com/adafruit/circuitpython/issues/6018"""
    while not supervisor.runtime.usb_connected:
        time.sleep(0.2)

def main():
    try:
        wait_for_usb()
        keyboard.go()
    except Exception as e:
        time.sleep(1)
        microcontroller.reset()

if __name__ == '__main__':
    main()

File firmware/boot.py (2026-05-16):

import board
import digitalio
from kmk.bootcfg import bootcfg

# Light up an LED during boot for some feedback.
meta_led = digitalio.DigitalInOut(board.GP28)
meta_led.switch_to_output(value=True)

# Fn+Esc is a normal reset (see code.py) 
# Fn+RShift+Esc (continuing to hold RShift diring boot) will enter programming mode.
bootcfg(
    sense=board.GP22, source=board.GP11, # Right shift key during boot enables serial and usb_drive.
    storage=False,
    cdc_console=False,
    midi=False,
    boot_device=1, # Let the keyboard be used in the BIOS.
    consumer_control=True,
    keyboard=True,
    mouse=True,
)

# Put things back how they were for code.py to run.
meta_led.value = 0
meta_led.deinit()

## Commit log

2022-05-26 Initial Commit.
    Schematic mostly done.
    PCB components arranged logically but needs laid out.
    [Rabid.kicad_pcb, Rabid.kicad_sch]
2022-05-27 Everything in its approximate location.
    TODO:
    - Still needs comparison to a real PCB to get measurements more accurate.
    - Needs mounting holes.
    [Rabid.kicad_pcb, Rabid.kicad_sch]
2022-05-27 Name the keys on F.Fab layer.
    [Rabid.kicad_pcb, Rabid.kicad_sch]
2022-05-27 Made measurements more precise.
    [Rabid.kicad_pcb]
2022-05-28 Add mounting holes.
    [Rabid.kicad_pcb, Rabid.kicad_sch]
2022-05-28 LED tracks routed.
    [Rabid.kicad_pcb, Rabid.kicad_sch]
2022-05-28 Tidy up the USB connector nets.
    [Rabid.kicad_pcb, Rabid.kicad_sch]
2022-05-29 Routed arrows keys and rows.
    [Rabid.kicad_pcb, Rabid.kicad_sch]
2022-05-29 Route columns. Board is now fully routed.
    [Rabid.kicad_pcb]
2022-05-29 Adjusted location of keys to match plate mount holes.
    [Rabid.kicad_pcb]
2022-05-29 Remove unused footprint library.
2022-05-29 Flip stabilizers on spacebar to fit on the board.
    Spacebar footprint is now broken out into its own library.
    [Rabid.kicad_pcb]
2022-05-29 Fixed several DRC errors.
    - Moved silkscreens into component footprints to keep them from overlapping.
    - Re-routed USB traces as a differential pair.
    [Rabid.kicad_pcb, Rabid.kicad_sch]
2022-05-29 Create a separate footprint for MX switches with LED.
    [Rabid.kicad_pcb, Rabid.kicad_sch]
2022-05-30 Changed dimensions, moved function row up, added mounting hole.
    [Rabid.kicad_pcb, Rabid.kicad_sch]
2022-05-30 Add GPIO/Debug header, bootsel, and reset switch.
    [Rabid.kicad_pcb, Rabid.kicad_sch]
2022-05-30 Add silkscreen labels and tidy microcontroller traces.
    [Rabid.kicad_pcb]
2022-05-30 Add project title/author/revision/url to silkscreen.
    [Rabid.kicad_pcb, Rabid.kicad_sch]
2022-05-31 Flip USB pinout to match original PCB.
    [Rabid.kicad_pcb, Rabid.kicad_sch]
2022-05-31 Change all mounting holes to 8.2mm diameter.
    [Rabid.kicad_pcb, Rabid.kicad_sch]
2022-05-31 Change DRC rules to match JLCPCB.
    - Fixed some DRC errors by adjusting tolerances.
    (Seems Kicad has some rounding error in differential pair gap DRC?)
    - Add "JLCJLCJLCJLC" to silkscreen for JLCPCB to replace with order number.
    - Slight adjustments to mounting holes.
    [Rabid.kicad_pcb, Rabid.kicad_sch]
2022-05-31 Add switch outline on back silkscreen for easier assembly.
    [Rabid.kicad_pcb]
2022-06-02 Make Filco mounting hole smaller.
    - Add logo under spacebar.
    - Change PCB colour to black.
    [Rabid.kicad_pcb, Rabid.kicad_sch]
2022-06-02 Change RP2040 Stamp footprint to throughhole.
    This ismore versatile as it allows either SMD or soldering on 2mm
    pinheaders to use as a socket.
    [Rabid.kicad_pcb]
2022-06-02 Make the power traces .7mm because I'm paranoid.
    [Rabid.kicad_pcb]
2022-06-03 Swap GPIO20 and GPIO21 (ROW0) pins.
    The RP2040 Stamp has a WS2812B LED on the GPIO21 line.
    It does have a jumper to disable the LED, but better to just work
    around it, so it remains usable.
    [Rabid.kicad_pcb, Rabid.kicad_sch]
2022-06-03 Change Filco hole from 4mm to 5mm.
    - Rename FnLock to MetaLock.
    - Minor silkscreen changes.
    [Rabid.kicad_pcb, Rabid.kicad_sch]
2022-06-03 Generate Gerbers and send to JLPCB.
    [Rabid-B_Cu.gbl, Rabid-B_Mask.gbs, Rabid-B_Paste.gbp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]
2022-06-09 Add plate cutouts to the User.1 layer.
    The intention is that this layer can be plotted as a Gerber and renamed
    to be the EdgeCuts. That way, the plate cutouts _always_ match the
    switch locations on the PCB.
    Cutout dimensions are heavily inspired by (read: stolen from) the
    awesome: http://builder.swillkb.com/
    Switch cutouts are square for maximum stability. Stabilizers are
    combined cherry/costar. Since this keyboard originally shipped with
    costar stabilizers, it's nice to keep compatibility.
    TODO: Add some extra margin around the edges of the plate so there
    aren't any thin lines at the edges.
    Double check the stab cutout dimensions with the Cherry MX datasheet.
    Consider adding the original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
    [Rabid.kicad_pcb, builder.swillkb.com.dxf]
2022-06-09 Add margin around the plate, LED and mount holes.
    [Rabid.kicad_pcb]
2022-06-10 Tweak plate size to match QFR case.
    [Rabid.kicad_pcb]
2022-06-12 Add holes in plate to press BootSel/Reset button.
    If the BootSel and Reset buttons don't fit in the case when installed on
    the back of the board, then they have a chance of fitting between the
    plate and PCB. A hole in the plate will let them be pressed with a small
    screwdriver.
    [Rabid.kicad_pcb]
2022-06-21 Add reference photos for QFR plate and controller.
2022-06-21 Reverse direction of row pins to match firmware.
    [Rabid.kicad_pcb, Rabid.kicad_sch]
2022-06-21 FW: Fix the column pins.
    [boot.py, code.py]
2022-06-28 Generate plate from the PCB Plate.Cutouts (User.1) layer.
    [RabidPlate-B_Cu.gbr, RabidPlate-B_Mask.gbr, RabidPlate-B_Paste.gbr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]
2022-06-28 Reorganize directory structure.
    Put the PCB in its own folder to keep it separate from plate and firmware.
    [Rabid-B_Cu.gbl, Rabid-B_Mask.gbs, Rabid-B_Paste.gbp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]
2022-06-28 Tidy up the gerber outputs.
    pcb/gerbers and plate/gerbers now contain the 1.0 version sent to JLCPCB
    for manufacture, along with the "production file"created by JLC.
    [Rabid-B_Cu.gbl, Rabid-B_Mask.gbs, Rabid-B_Paste.gbp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]
2022-07-17 PCB: Move D5 and D80 over just a bit so they don't interfere with stabilizers
    [Rabid.kicad_pcb]
2022-07-17 PCB: Swap Reset and BootSel button silkscreens.
    [Rabid.kicad_pcb, Rabid.kicad_sch]
2022-07-27 USB: Add QFR USB board reference photos.
2022-07-27 USB: Initial commit of QFR (costar) USB-C daughterboard.
    [RabidUsb_costar.kicad_pcb, RabidUsb_costar.kicad_sch]
2022-07-27 USB: Update tooling holes to match what JLCPCB needed for assembly.
    [RabidUsb_costar.kicad_pcb]
2022-08-07 USB: Initial commit of YMDK USB-C daughterboard.
    [RabidUsb_ymdk.kicad_pcb, RabidUsb_ymdk.kicad_sch]
2022-08-07 Tidy up JLCPCB production files.
    [bom.xls]
2022-08-08 USB: More ground plane between VCC and D+/D-.
    [RabidUsb_costar.kicad_pcb, RabidUsb_ymdk.kicad_pcb]
2022-08-24 USB: Add ferrite beads to YMDK USB board.
    [RabidUsb_ymdk.kicad_pcb, RabidUsb_ymdk.kicad_sch]
2022-09-12 USB: Add production files for usb_ymdk board.
2022-09-14 USB: Add 3D models for USB connector and fuse.
    [RabidUsb_costar.kicad_pcb, RabidUsb_ymdk.kicad_pcb]
2022-09-14 USB: Add ferrite beads to usb_costar board as well.
    [RabidUsb_costar.kicad_pcb, RabidUsb_costar.kicad_sch]
2022-09-14 Add images/renders of all boards and schematics.
2022-09-14 USB: Move usb_ymdk holes up a couple thou.
    This should helpfully give some more room, so the board isn't such a
    tight fit in the YMDK F87 case.
    [RabidUsb_ymdk.kicad_pcb]
2023-01-17 FW: Add more robust error handling.
    1) On startup, the board now waits for USB to be connected. This works
    around a quirk in CircuitPython where accessing USB before it's ready
    causes Windows to give up with the error:: "Unknown USB device (device
    descriptor request failed)".
    2) When an exception unwinds all the way to main(), the error message is
    written to flash and a reset is attempted after a delay. This reset
    allows the keyboard to recover from static shocks where the host and
    keyboard briefly lose contact with each other.
    [boot.py, code.py]
2023-01-17 FW: Support CircuitPython 8.0beta6.
    The `next_stack_limit` had a minor API change.
    This supports both 7.0 and 8.0 for now.
2023-02-03 PCB: Add a ground pour to both sides of the board.
    There's a via near each key. Hopefully this fixes issue #1.
2024-09-26 Add macro recording.
    Select macro slot: Fn+Number
    Record: Fn+`
    Stop recording: Fn+Backspace
    Play: Fn+Return
2024-09-26 Remove stack limit from boot.py.
    This doesn't seem to be required with recent versions of KMK and
    CircuitPython >=9.0.
    [boot.py]
2025-04-07 FW: Fix to run against latest KMK.
    [code.py]
2025-04-10 FW: Pulse the scroll lock LED when the mouse jiggler is on.
2025-04-10 FW: Remove error logging now that KMK catches exceptions.
    https://github.com/KMKfw/kmk_firmware/commit/e79414e0582b81de98c9a0fce57988da292a0f39
    [code.py]
2025-04-10 FW: Throttle LED status updates and fix a float precision bug.
    [code.py]
2026-05-16 FW: Minor updates.
    - Make self.matrix a list to avoid a fallback codepath in KMK.
    - Keep the Fn-lock LED lit when the layer is selected an Fn is pressed.
    -Import `Pin` since we use type annotations.
    [boot.py, code.py]
